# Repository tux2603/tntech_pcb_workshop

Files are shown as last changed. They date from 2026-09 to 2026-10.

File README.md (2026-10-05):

# tntech_pcb_workshop

Files and references for a PCB design workshop at Tennessee Tech. The workshop will focus on designing and assembling a two-layer PCB for a simple Arduino-compatible STM32 development board, and will serve as a first-introduction to PCB design and assembly for students. Students are expected to have a familiarity with basic electrical engineering concepts such as Ohm's law, impedance, and basic circuit analysis, but no prior experience with PCB design is required. The workshop will be hands-on, and will culminate in students assembling a (hopefully) functional PCB that they will be able to take home with them.

Additional information can be found in the [documentation](documentation/main.md) for the workshop. Slides shown in the workshop can be found in the [slides](documentation/slides/main.md) section of the documentation.

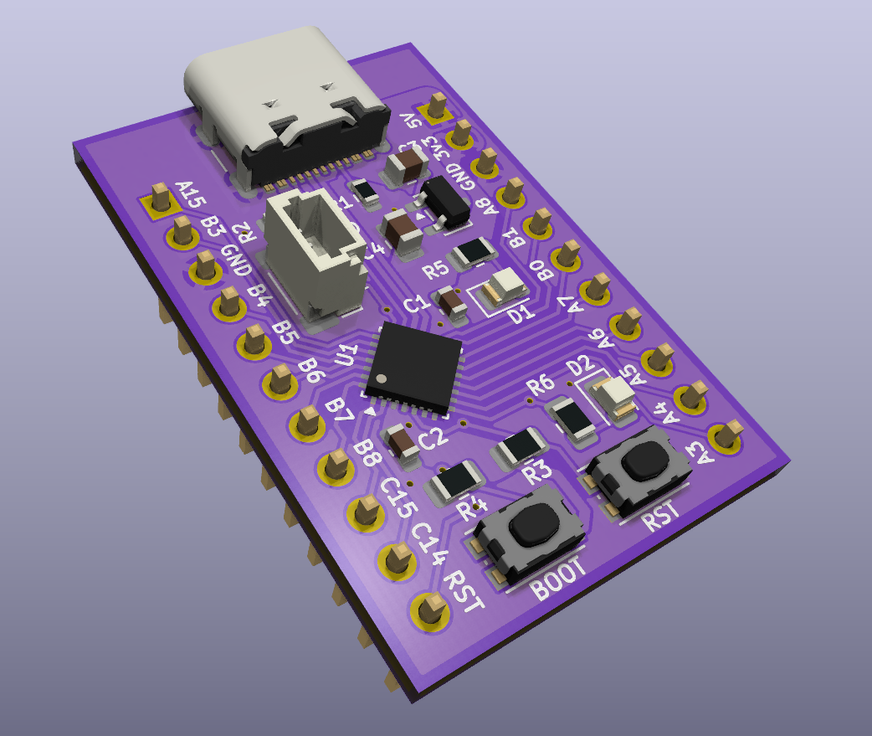
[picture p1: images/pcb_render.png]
PCB render


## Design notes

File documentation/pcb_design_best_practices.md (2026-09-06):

# Best Practices for PCB Designs

## 1. Designing with manufacturability and assembly in mind

A PCB isn't terribly useful if it only exists as some ones and zeroes on your computer. At every stage of the design process, you should be thinking about how your design will be manufactured, and if anything you're doing will make it difficult or impossible to produce. 

### 1.1 Design rules and other manufacturing considerations

- **Pick a target manufacturer early.** Every manufacturer has slightly different capabilities, which will affect many design decisions you make as you design the PCB. By picking a manufacturer early, you can make sure that your design is compatible with their capabilities, and avoid having to rework your design later.

- **Set up your design rules to match the capabilities of your manufacturer.** This is one of the most important steps in PCB design, and should be done before you start layout or routing. this includes minimum trace width and spacing, via sizes, and what sorts of vias are supported. Manufacturers can not reliably produce a PCB that violates their design rules, so if you don't set up your design rules correctly, you will almost certainly have to go back and rework your design before it can be manufactured. This sort of rework can be very time consuming and frustrating, so it's best to avoid it by setting up your design rules correctly from the start and checking them frequently as you work on your design.

- **Pick a stack-up early and stick with it.** A stack-up is the arrangement of copper and insulating layers in your PCB, along with a plan for how each copper layer will be used. The stack-up will affect the electrical performance of your design, the required traced widths for impedance-controlled signals, how easy it is to route your design, and the overall cost of manufacturing. Stack-ups will typically have one or more signal layers, each with a corresponding ground plane, and potentially one or more power planes. 

- **Avoid using the extreme limits of your manufacturer's capabilities when it's not necessary**. The capabilities of your manufacturer are only an absolute limit to what can be done. Just because your manufacturer can make 4 mil wide traces with 4 mil spacing doesn't mean that all your traces should be that small. Unless there is a specific reason to use a certain width trace, there's no reason to make your traces as small as possible. Wider traces are easier to manufacture, are more robust, and are easier to fix if something goes wrong. Set your default trace width to something reasonable, like 0.2-0.3 mm (~10 mil), and only use smaller traces when you have a reason to do so. Similarly, don't use the smallest possible via sizes unless you have a reason to do so.

- **Don't use high-end features like blind vias or super fine pitch traces unless you are sure that you need them for a design.** High-end features likes these can make a complex design possible, but will also cause the cost of manufacturing to skyrocket. If you can get away with the "lowest-tier" capabilities of your manufacturer, you should.

### 1.2 Component and footprint selection

- **Select components and footprints that are realistic for your assembly method.** If you are hand soldering, do not use tiny 0201 components. You _technically_ can solder them by hand, but it will be a nightmare. Through-hole components are easier to solder by hand, but they take up more space and are often more expensive.

- **Make sure that you have the right footprint for your selected components.** Components are often available in multiple different package types, each of which will require a different footprint on your PCB. Make sure that the footprint you are using matches the package type of the component that your are buying. If you are using a footprint that you found online, make sure to double check the dimensions of the footprint against the datasheet for the component to make sure that it is correct. 

- **Avoid using components that are difficult or cumbersome to source.** Doing this well takes a little experience, but you can get a basic idea of what is easy to source by looking at the stock levels and lifecycle of the components you are considering. If one option has 10,000 units in stock and another has 10, it is very likely that the first option will be more reliable to source in the long run. Similarly, if a component is marked as something like "End of Life," "Obsolete, "or "Not Recommended for New Designs", it will be extremely difficult to source in the future, and you should avoid using it if at all possible.

- **Avoid "Marketplace" style vendors when possible.** On sites like Digikey and Mouser, there are often "Marketplace" parts available at a lower price. These parts are typically sold and shipped by third-party sellers. They can potentially bring the overall cost of your design down, but will often have longer shipping times and require you to pay separate shipping charges. If you are on a tight schedule, it is often better to avoid marketplace parts.

### 1.3 Assembly considerations

- **Make sure that the pads for your components are on the correct layers.** You can't solder a component to a pad that is in the middle of a PCB. This means that your pads must be on either the top or bottom layer unless you are doing a very complex and extremely expensive custom designs.

- **Prefer to keep surface mount parts all on the same side of the board.** Single-sided assembly is cheaper and easier than double-sided assembly. If it doesn't matter what side of a board a component is on, pick a default side and stick with it. Typically the top layer is the standard for surface mount parts, but if it makes more sense to you to put everything on the bottom, that's fine too. Just make sure that you are consistent.

- **Avoid placing components too close together.** If components are too close together it can be extremely difficult to solder them, especially if you are hand soldering. Keep a reasonable buffer between components.

- **Avoid placing components too close to the edge of the board.** If components are too close to the edge of the board, they can be damaged during assembly or when the board is being handled. Unless your component needs to be on the edge of the board, for example if it's a connector or a button, keep them a reasonable distance back.

## 2. Designing with electrical performance in mind

While low-speed, low-power designs can often get away with a lot of "sloppy" design practices, high-speed or high-power designs will require careful attention to detail in order to function correctly. Even if your design is low-speed and low-power, it is still a good idea to follow best practices for electrical performance in order to form good habits that will carry over to more complex designs in the future.

### 2.1 Power distribution

- **Use a ground plane.** A ground plane is a large area of copper that is connected to the ground net of your design. A ground plane provides a reliable, low-impedance return path for signals and will make your design more robust to noise and interference and (hopefully) easier to route. On 4+ layer boards, it is extremely common to dedicate one or more entire layers to a solid ground plane. On 2-layer boards, it is a bit harder to dedicate an entire layer to a ground plane, but it is still extremely common to have one layer be mostly ground with as few other traces as possible. I can not stress enough how useful a ground plane is. Use a ground plane.

- **Use a "star" topology instead of a "daisy chain" topology for power distribution as much as possible.** A star topology is one where all the power connections to your components fan out from a single point, while a daisy chain topology is one where the power connections to your components are connected with a single trace, one after the other. A daisy chain topology will typically be easier to route, so it can be very tempting to use, but it can cause problems with accumulating voltage drops and noise as power travels down the chain. A star topology will typically require a bit more routing work, but will provide your components with a more stable and reliable power supply.

- **Use proper trace thicknesses based on your power needs.** If you are designing a high-power circuit, it is important to use traces that are thick enough to handle the current without overheating or causing voltage drops. There are many online calculators available that can help you determine the appropriate trace width based on the current and the thickness of your PCB copper layer.

- **Use decoupling capacitors near your ICs.** ICs will often draw large spikes of current as they switch states, which can cause glitches and brown-outs if your power distribution network isn't able to supply that current quickly enough. Decoupling capacitors are small capacitors placed as close to an IC's power pins as possible, and act as a local reservoir of charge that can supply the IC with power during these spikes. A good rule of thumb is to use a 0.1uF (100nF) ceramic capacitor for each power pin of an IC unless the IC's datasheet specifies otherwise. Connect one end of the decoupling capacitor to the IC's power pin, and connect the other end to the nearest ground plane.

### 2.2 Signal integrity

- **Route traces carrying your fastest/most sensitive signals first.** High-speed and impedance controlled signals will typically have the strictest routing requirements, so it is a good idea to get them out of the way first. Once you get traces routed for your high-speed signals, you can move on to routing traces for the rest of your signals.

- **Reference high-speed signals to an uninterrupted ground plane.** Anytime you have a current flowing through a trace, there must be a corresponding current flowing back to the source. If that current doesn't exist, it means that KCL is messed up and the universe has broken. Once the frequency components of a signal get high enough, this return current will no longer just follow the path of least resistance, but will instead follow the path of least impedance. The means that when you have a high-speed signal traveling along a trace, the return current will want to flow directly below that trace through the ground plane. If there is no ground plane below the trace or if the ground plane is interrupted by a gap, hole, or some other trace running through it, the return current will have to find some other path back to the source. This path is incredibly hard to predict, and can cause all sorts of problems with signal integrity, including reflections, crosstalk, and EMI.

- **Prefer referencing low-speed signals to a ground plane.** Low speed signals are not as sensitive to signal integrity issues as high-speed signals, but it is still a good idea to reference them to a ground plane whenever possible. It is possible to reference them to a power plane if a design requires it, but this is not ideal. If you do reference a low-speed signal to a power plane, make sure that you have decoupling capacitors close to the signal's source and load to complete the return path for the signal.

- **Use appropriate trace widths for impedance-controlled signals.** The width and spacing of a trace will affect the impedance that it presents to signals traveling along it. If you have an impedance mismatch between a trace carrying a high-speed signal and the source or load that it is connected to, you will get reflections and other signal integrity issues. Calculate the required trace width and spacing for your impedance controlled signals based on your PCB stack-up before you start routing, and make sure to use those widths and spacings when routing those traces.

- **Route differential pairs together and maintain their spacing.** Differential pairs are sets of two traces that carry a set of complementary signals. Differential pairs are often used for high-speed signals because they offer better noise immunity and produce less noise themselves. When routing differential pairs, it is important to keep the two traces close together and maintain a consistent spacing between them. 

## 3. Designing with testing and debugging in mind

### 3.1 Test points and indicators

- **Include indicator LEDs in your design.** In almost every situation, it is a good idea to include indicator LEDs in your design. LEDs, especially surface-mount LEDs, are extremely cheap and can provide an easy visual indicator of things like power, status, and detected errors. If you have any sort of power regulation in your design, it is a good idea to include a power indicator LED. If your design is using some for of microcontroller, it is a good idea to use spare GPIO pins from that microcontroller to drive status LEDs. It's a lot faster to glance at a board and see that an LED is lit or blinking than it is to grab a multimeter or oscilloscope and start probing around to try and figure out what is going on.

- **Include test points for important nets on your PCB.** While status LEDs are useful, you sometimes do need a bit more information than a simple on/off indicator can provide. In these situations, it is a good idea to include test points in your design. Test points are small pads that are connected to important signals or power planes, and provide a convenient place to probe with a multimeter or oscilloscope

### 3.2 Documentation

- **Keep track of design decisions and changes.** Documenting your design decisions and any changes made during the design process is crucial for maintaining a clear understanding of the design and for future reference. You don't want to go back to your design a few weeks later and try to remember if there was a reason you're using a 19k resistor, or if it was just a typo.

- **Use silkscreen labels as much as possible** Silkscreen labels are the text and symbols printed on the surface of your PCB. They can be used to label components, indicate pin numbers, and provide other useful information. If you have extra space, mark down what pins are being used for what purpose, or any other useful information. This will make it easier to debug your design later, and will also make it easier for someone else to understand your design if they need to work on it in the future.

- **Use version control for your PCB design files.** Version control, such as git, is a system that makes it easy to track changes to files over time. Using version control will not only provide an overview of the changes you've made over time, but will also make it easier to revert to a previous version of your design if you make a mistake or decide that the changes you made weren't actually necessary. 

### 3.3 "Flexible" design

- **Design your PCB to be easily modified post-manufacturing.** Chances are the first iteration of a PCB design will not be perfect, and you'll likely have to make some tweaks. For prototypes, you can work in some design elements to make these tweaks easier. Typically, this will mean leaving some extra space around components, using thicker traces, providing test pads for important nets, and avoiding routing signals on internal layers. Copper is effectively free on a PCB, so there's not much reason to be stingy with it. If you have the space, use it to make your design easier to tweak.

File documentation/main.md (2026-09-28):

# Tennessee Tech PCB Design Workshop

## Overview

This workshop is designed to provide hands-on experience with PCB design and manufacturing processes. Participants will learn how to design a PCB using industry-standard software, understand the manufacturing process, and how to follow best practices for creating reliable and efficient PCB layouts. Due to time constraints, this workshop will not go over schematic capture or simulation, nor will it cover advanced topics such as high-speed design, RF design, or power electronics. Instead, the focus will be on the fundamentals of PCB design, including layout techniques, component placement, routing strategies, and design for manufacturability.

In the workshop, participants will be guided through the process of designing a simple PCB starting from a provided schematic. The goal will be to create a functional PCB layout that can be manufactured and assembled. The schematic used in this workshop is a simple microcontroller dev-board based on the STM32C071RB6N from STMicroelectronics. This microcontroller is a 32-bit ARM Cortex-M0+ device capable of running at up to 48 MHz with 128 kB of flash memory, 16 kB of SRAM. This device is suitable for a wide range of applications, and was selected because it can be programmed using a built-in USB DFU bootloader without the need for an external crystal or expensive programming tools. The final board can be programmed directly from the Arduino IDE, but will also work with other programming environments such as PlatformIO, STM32CubeIDE, and Keil MDK.

## Workshop Goals

By the end of this workshop, participants will be able to:
- Understand the basics of PCB design and layout.
- Use PCB design software to create a PCB layout from a schematic.
- Apply best practices for component placement, routing, and design for manufacturability.
- Prepare a PCB design for manufacturing, including generating Gerber files and a Bill of Materials (BOM).
- Assemble and test a simple PCB design.

## Workshop Materials and Resources

The only thing that participants will need to bring to the workshop is a laptop with KiCad 10.0 installed. KiCad is a free and open-source PCB design software that is widely used, both in the industry and by hobbysists. KiCad is available for Windows, MacOS, and Linux, and can be downloaded from the official KiCad website: [https://kicad.org/download/](https://kicad.org/download/). Participants are encouraged to install KiCad prior to the workshop to ensure that they have the latest version and that it is working properly on their system. All other materials, including the PCB and all components needed for the workshop, will be provided by the workshop organizers.

If you would like to assemble the PCB after the workshop, all of the parts are available for purchase from DigiKey, Mouser, or other electronics distributors. A boll of materials (BOM) for the PCB is provided [In this repository](../Tech%20PCB%20BOM.csv), and a DigiKey parts list is available [here](https://www.digikey.com/en/mylists/list/NAWFEKVTE1). Additional PCBs can be purcased from any major PCB manufacturer, such as [JLCPCB](https://jlcpcb.com/), [PCBWay](https://www.pcbway.com/), [OSH Park](https://oshpark.com/), or [DKRed](https://www.digikey.com/en/resources/dkred).

A quick reference guide to PCB design best practices can be found in the [PCB Design Best Practices](pcb_design_best_practices.md) document. Slides from the workshop will be uploaded in the future.

## External Resources

- **[KiCad Documentation](https://docs.kicad.org/)**: The official documentation for KiCad, including tutorials and reference materials.
- **[Phil's Lab YouTube Channel](https://www.youtube.com/@PhilsLab)**: A YouTube channel with tutorials and videos on PCB design, electronics, and related topics.

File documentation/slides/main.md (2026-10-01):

# Workshop Slides

- **Session 1**: [PCB Design intro and best practices](s1_slides.pdf)

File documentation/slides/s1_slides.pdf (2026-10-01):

# Tennessee Tech PCB Design Workshop

Owen O’Connor (ococonnor42@tntech.edu)

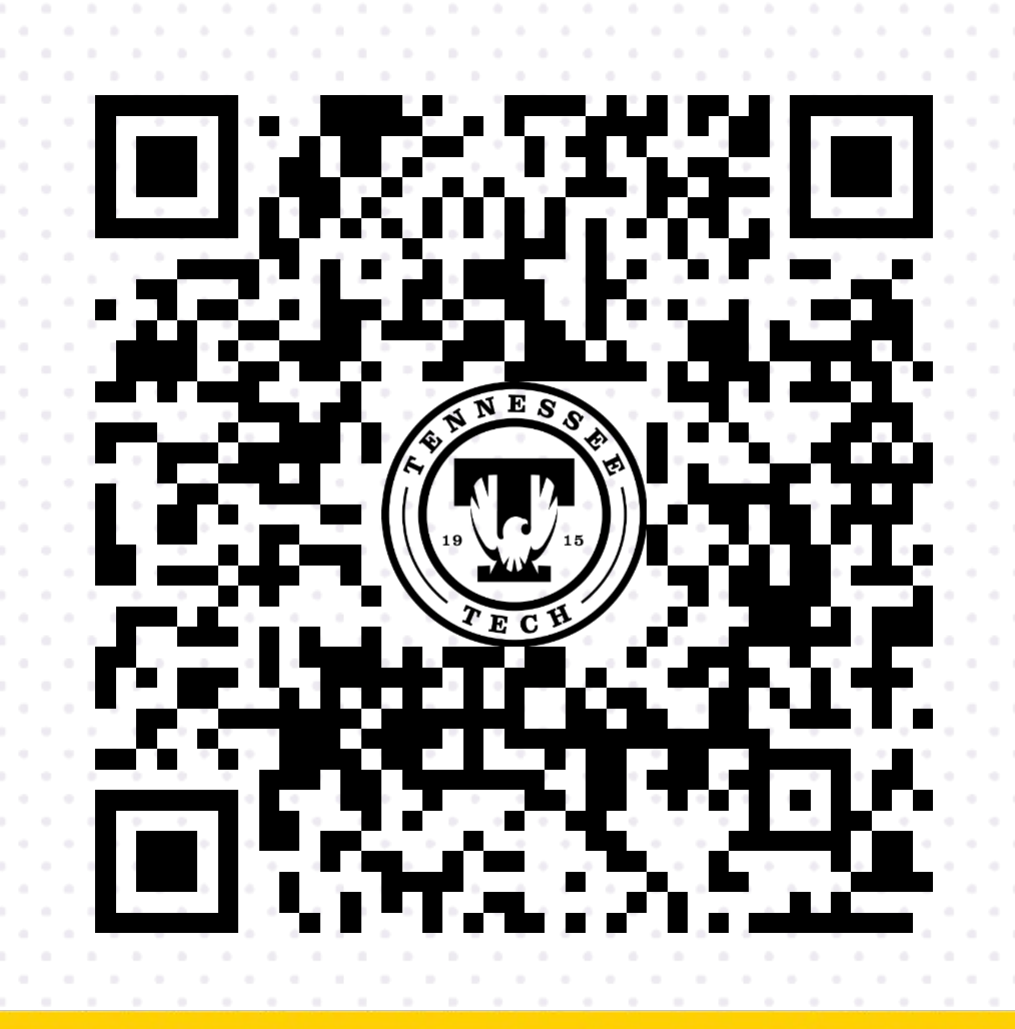
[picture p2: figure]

1

## Workshop Overview

- PCB Design Principles and Practices (1 October) ← today!
- PCB Design Time in KiCad (6 October)
- PCB Design Time in KiCad (8 October)
- PCB Assembly and Testing (13 October*)

*tentative date

2

## Workshop Goals

- Why and when to use PCBs
- PCB design best practices
- Using PCB design software
- Assembling PCBs

3

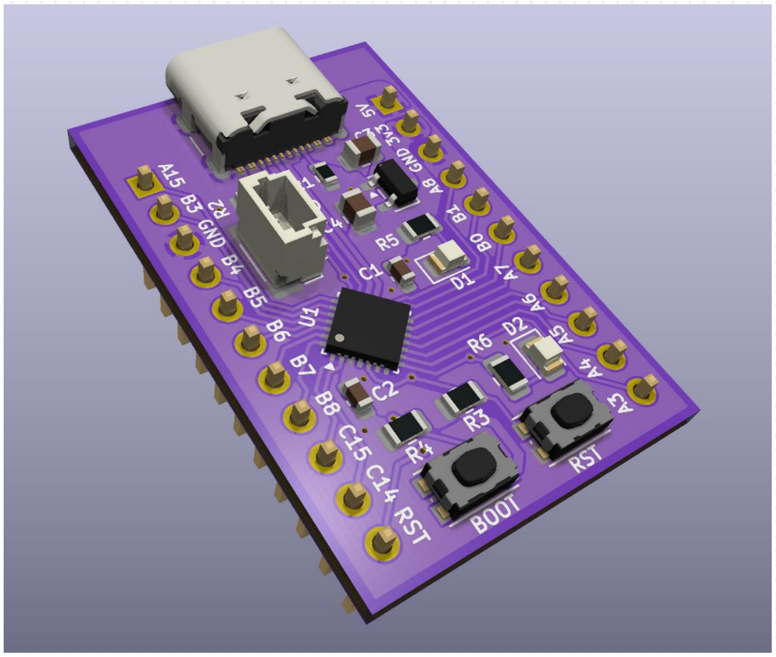
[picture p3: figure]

## Our Project

STM32 board,
Arduino-compatible
- USB-C
- 17 (kinda 18) GPIO
- Built in LED
- Debug Header

4

## Today’s Goals

- Understand why PCBs are important
- Learn the PCB design workflow
- PCB design best practices
- How to install KiCad

5

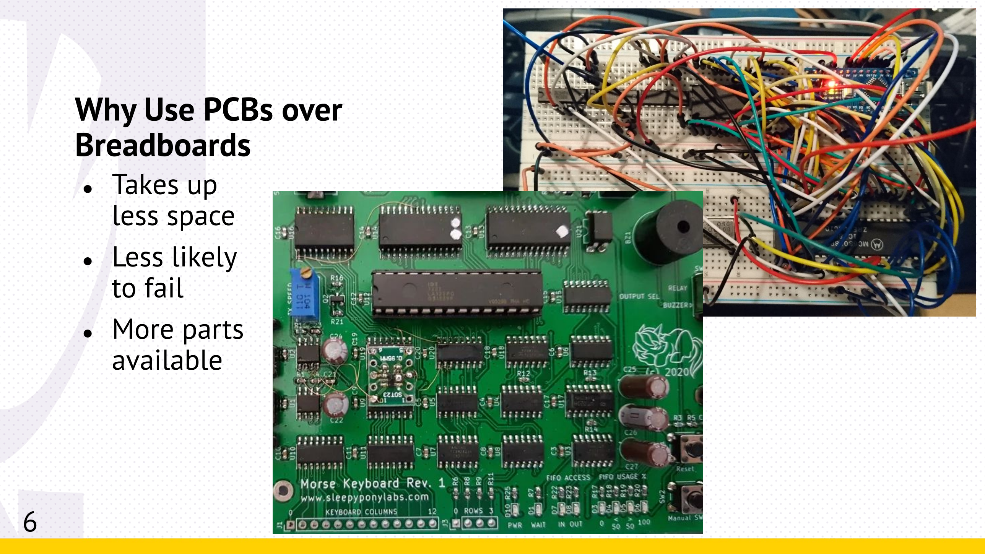
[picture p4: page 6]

### Why Use PCBs over Breadboards

- Takes up
less space
- Less likely
to fail
- More parts
available

6

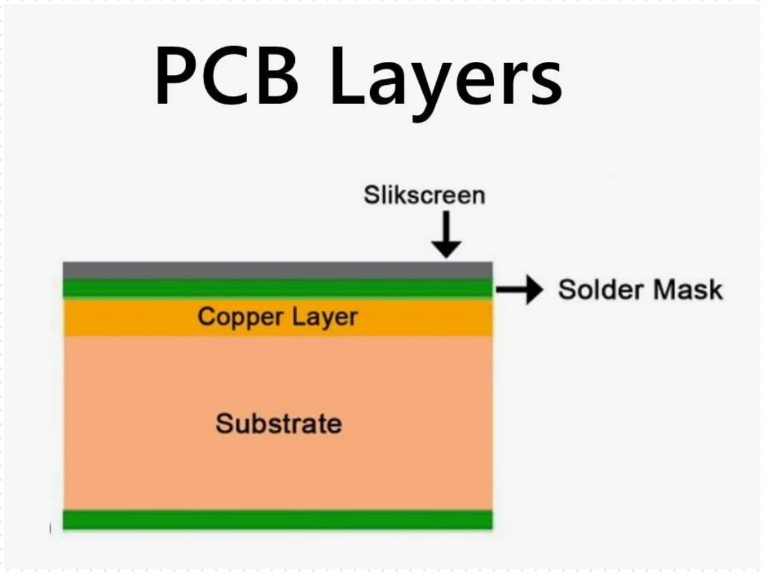
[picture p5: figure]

### Layers of a PCB

- Copper
- Substrate
- Solder mask
- Silkscreen

7

### Features on a PCB

- Pad
- Trace
- Via
- Plane
- Footprint

8

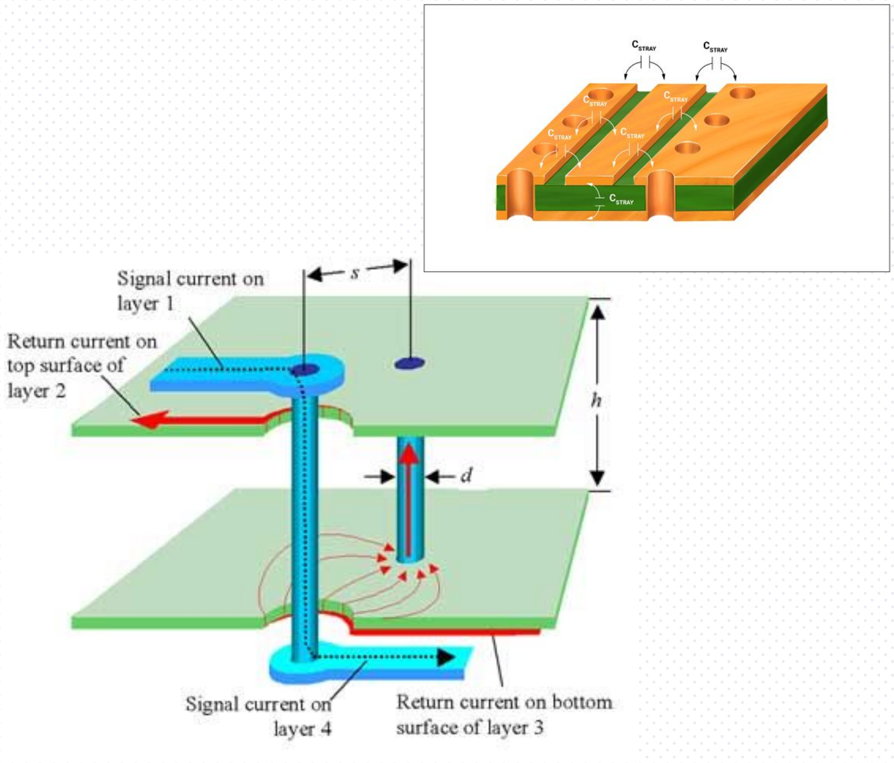
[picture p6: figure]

### The Electrical Behavior of a PCB

- Return currents (low
vs high speed)
- Current loops
- Parasitic capacitance

9

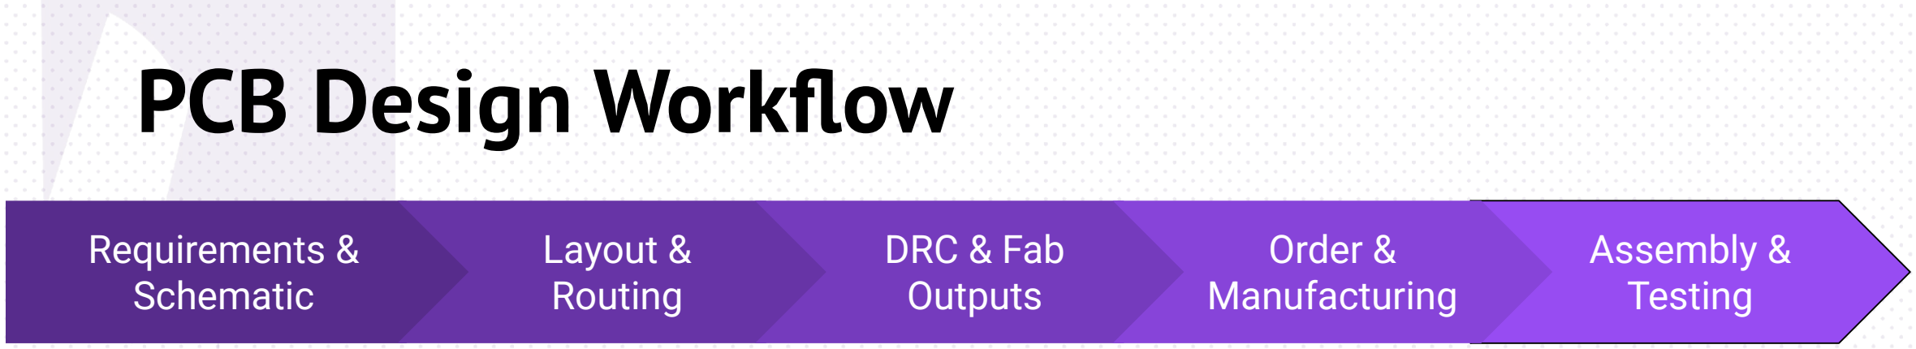
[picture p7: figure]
PCB Design Workflow; Requirements & Schematic; Layout & Routing; DRC & Fab Outputs; Assembly & Testing; Order & Manufacturing

- Figure out what
the board does
- Figure out how
to do that thing
- Plan out how to
connect
everything in
order to do that
thing
- Defines the
physical size of
the board
- Plan the layout
so routing is
easy
- Route traces to
connect
everything
together
- Verify that your
design can be
made
- Export the
design files for
sharing
- Place and solder
components
- Test for shorts and
connections
- Upload any code,
verify functionality
- Upload exported
design files
- Fill out requested
specs and
features
- Place order

10

## Schematics

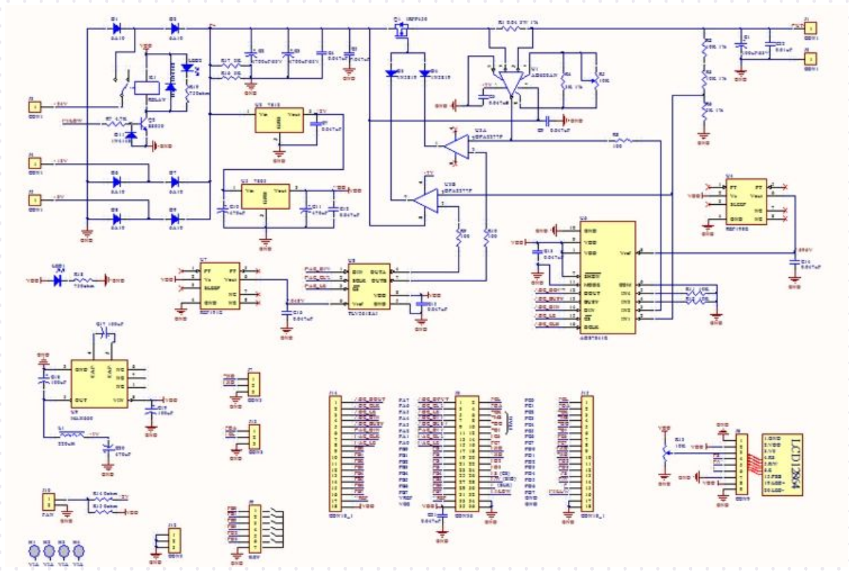
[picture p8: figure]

Left to right flow
Power is up, ground is down Group by function
Documentation!

11

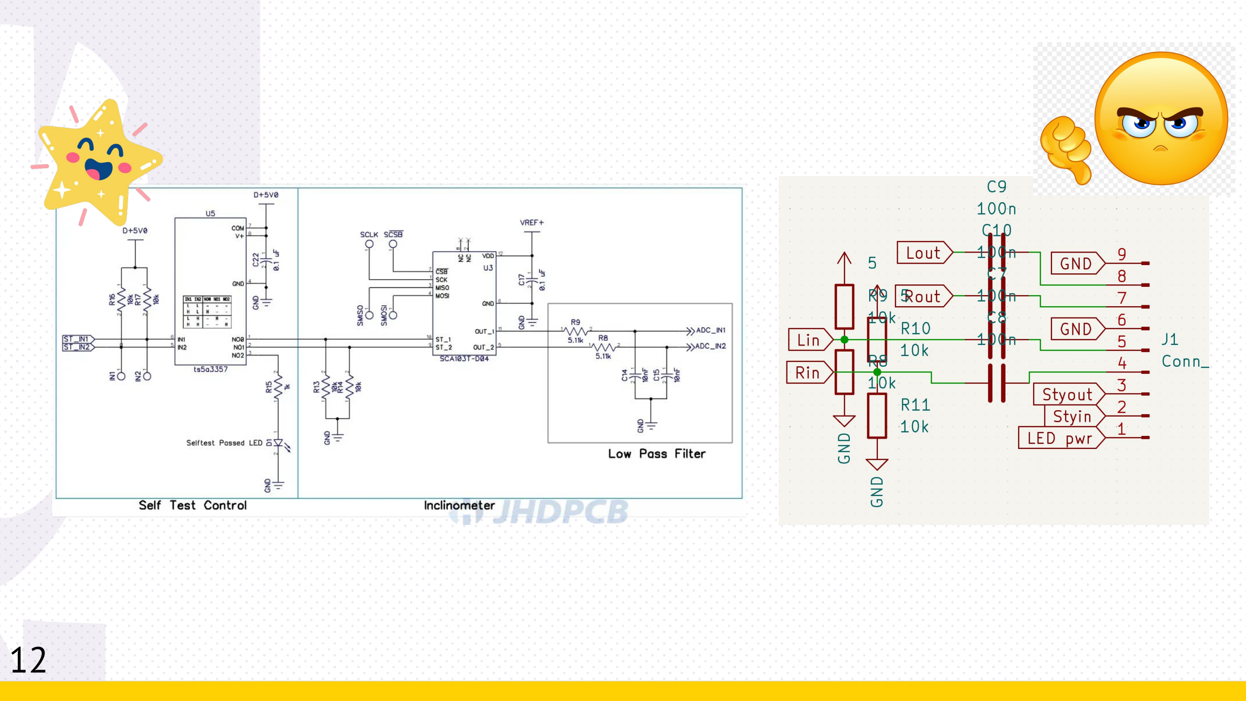
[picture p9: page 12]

12

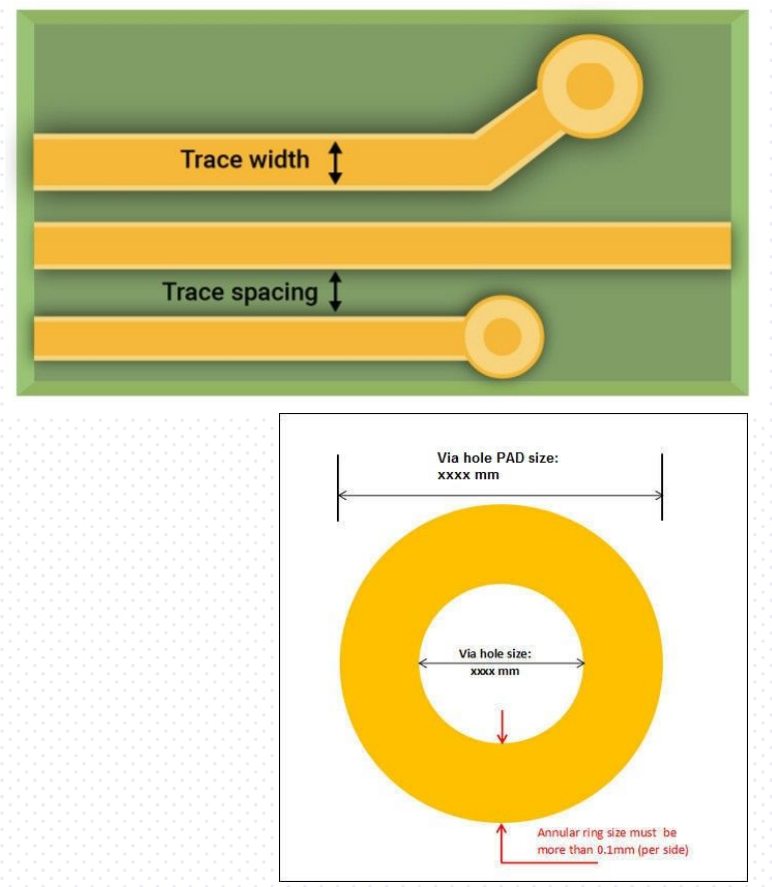
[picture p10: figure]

## Design Rules

Always set these up!
- Minimum trace width/spacing
- Minimum via size
- Clearance requirements
- Etc

Minimums are just minimums! Typically you want to use greater than the minimum
13

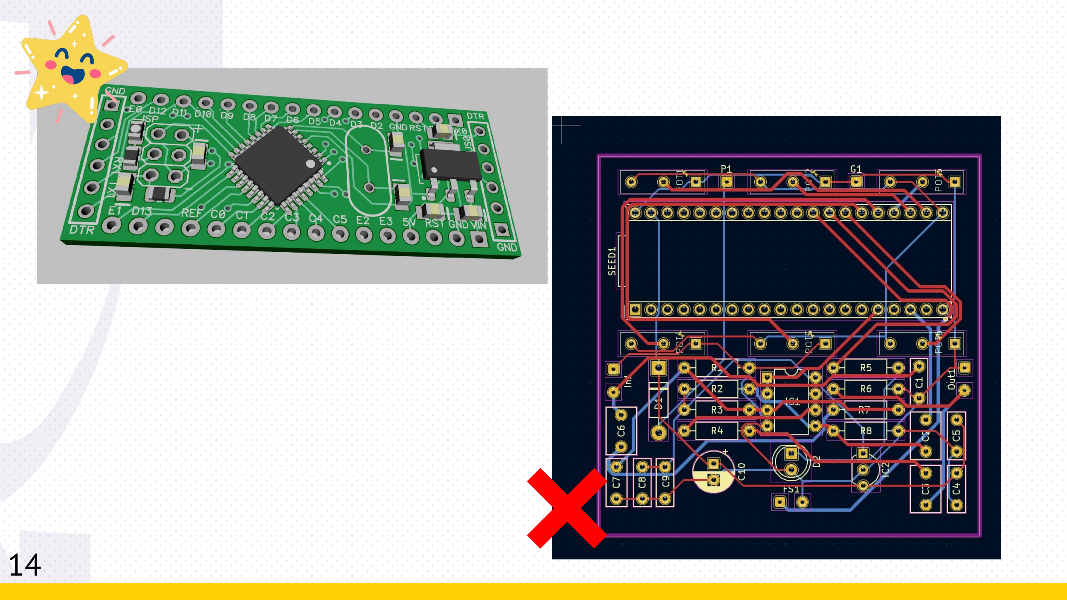
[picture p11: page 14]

14

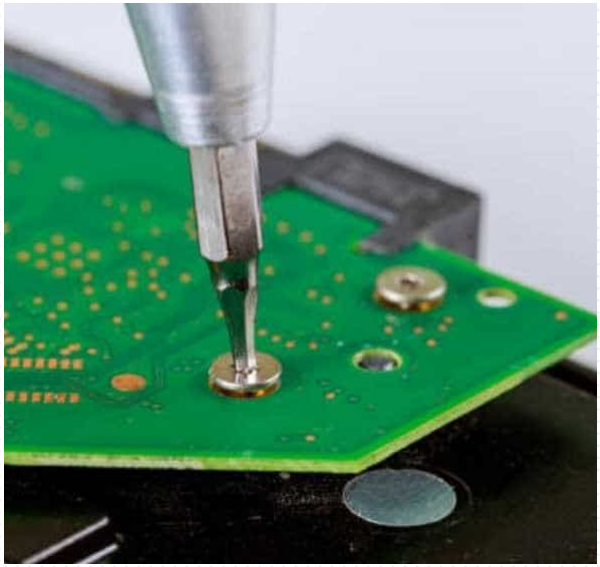
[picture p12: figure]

## Physical Aspects

Outline/edge cuts
Connector placement
Mounting holes

15

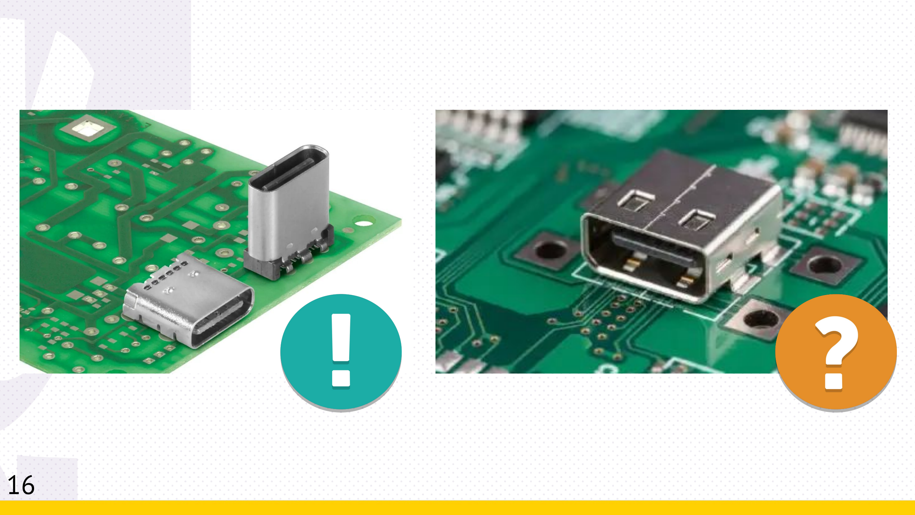
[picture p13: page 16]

16

## Stack up

Number of layers
Purpose of each layer
Common stackups:

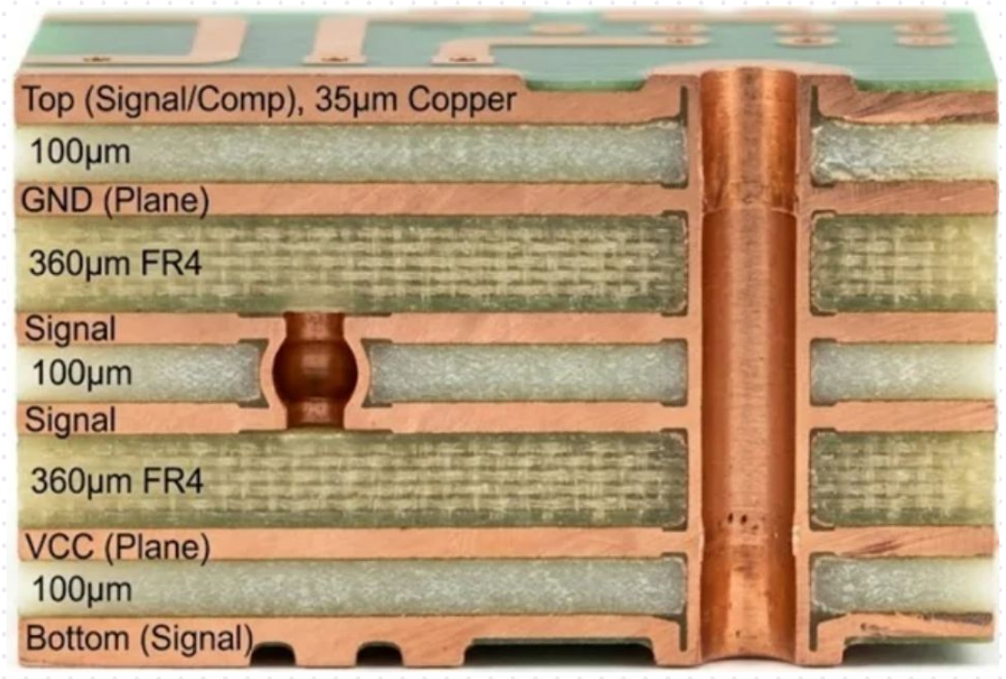
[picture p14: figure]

2 Layer | 4 Layer | 6 Layer

Sig+PWR
GND

Sig+PWR
Sig+GND

Sig
| GND GND

Sig

Sig
| GND PWR Sig (slow)

Sig
| | GND PWR

Sig
| | GND
Sig

Sig
Gnd
Sig
Sig
Pwr
Sig 17

## Footprint/Component Selection

Choose appropriate footprints
Check dimensions from against the data sheet Check pin orders on multi-pin parts

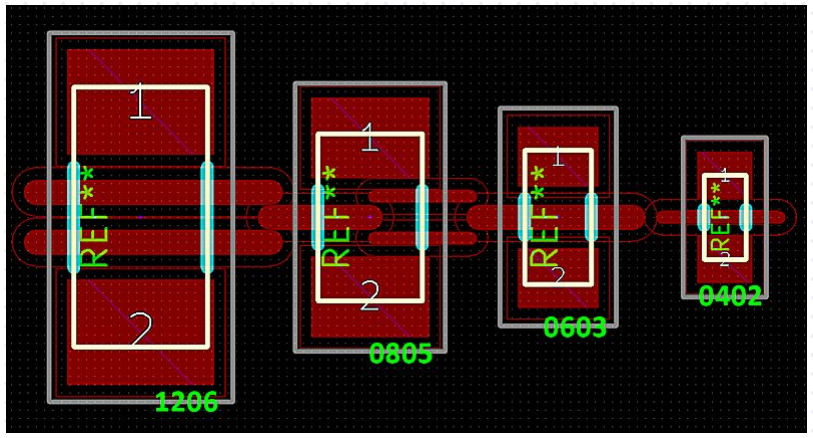
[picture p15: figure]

Note: The number refers to the dimensions of the 18 component (ex. 0603 => 60x30 thousandths of an inch)

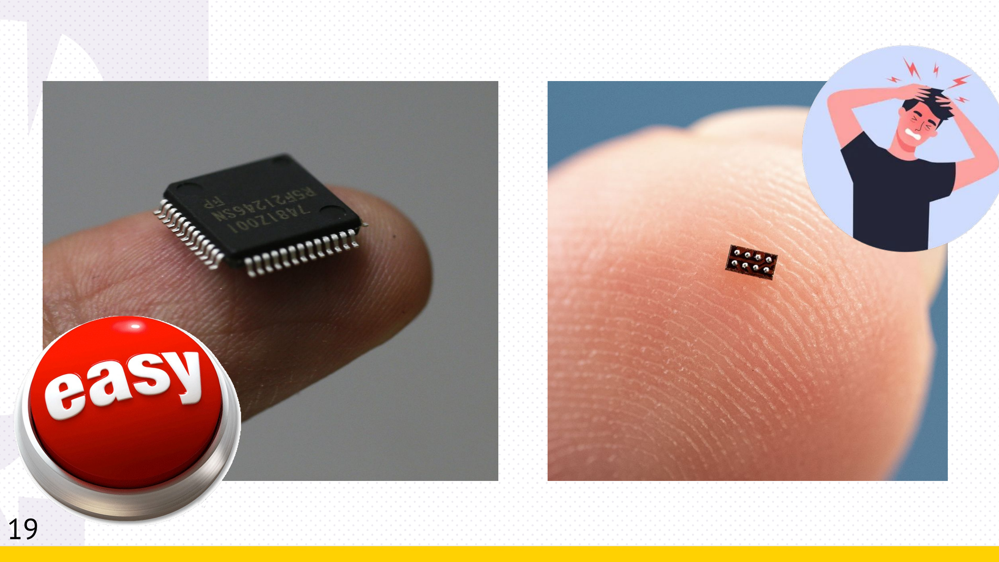
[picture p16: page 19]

19

## Layout

- Placement by functional groups
- Decoupling caps
- Minimize ratline crossing

Falstad Simulation (https://falstad.com/circuit/circuitjs.html) of decoupling capacitor

20

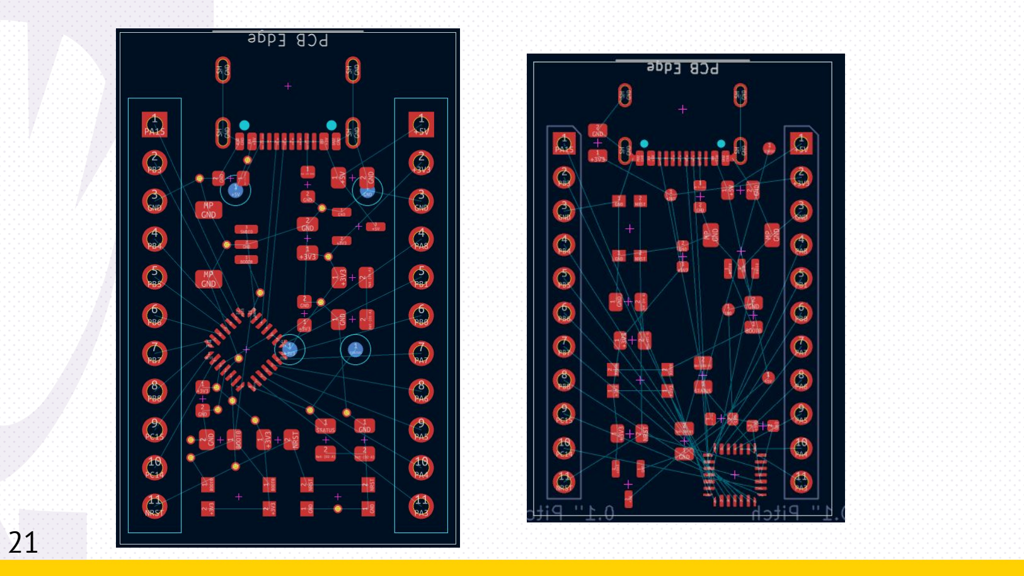
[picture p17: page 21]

21

## Power Distribution

- Solid ground plane whenever possible
- Solid power plane when you can
- Star instead of daisy chain power distribution
- (again) Decoupling capacitors!

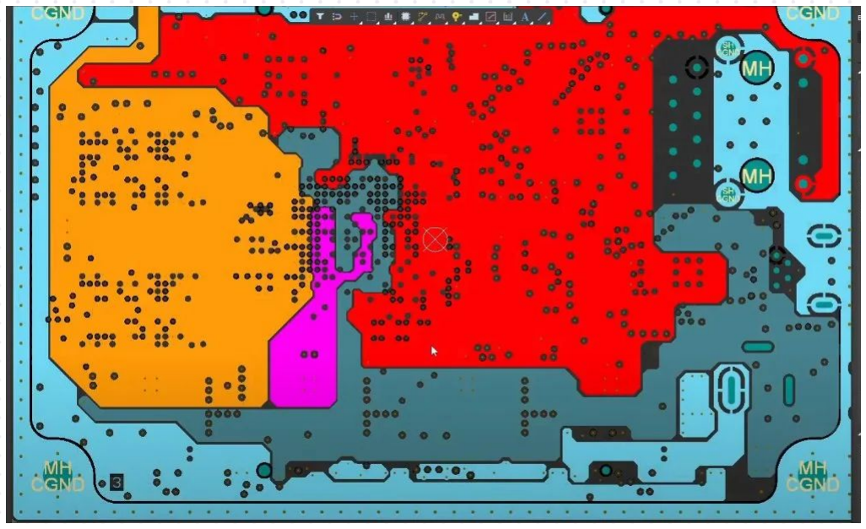
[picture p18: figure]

22

## Signal Integrity and Reliability

- Decoupling caps close to all ICs (this is important)
- Reference plane for high speed signals
- Place and route most sensitive signals first
- Impedance/length matching

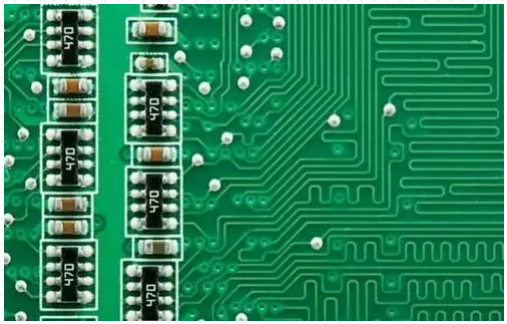
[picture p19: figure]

23

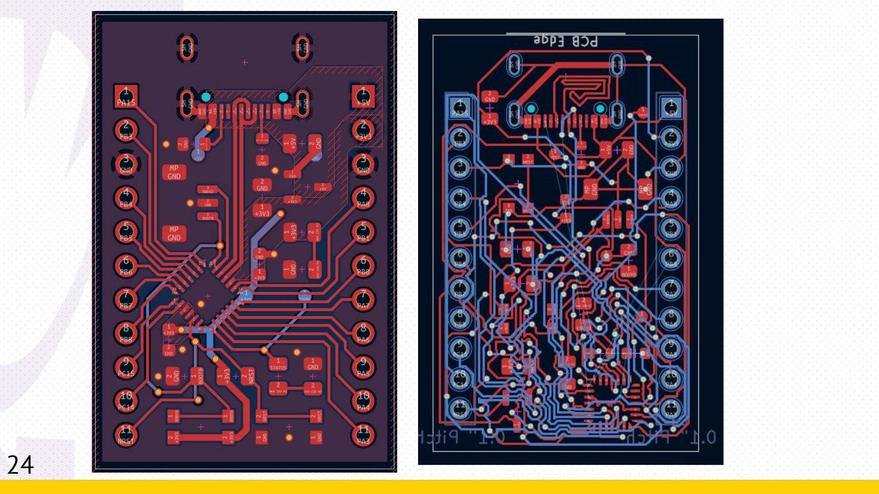
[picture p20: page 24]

24

## Manufacturability

- No vias in pads!
- Have some space between components
- Aim for one-sided designs

25

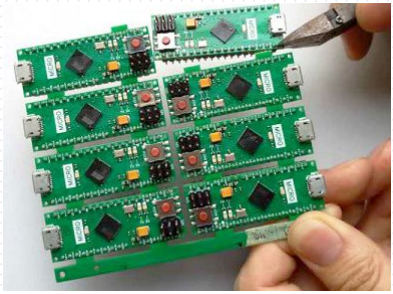
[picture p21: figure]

## Debuggable Designs

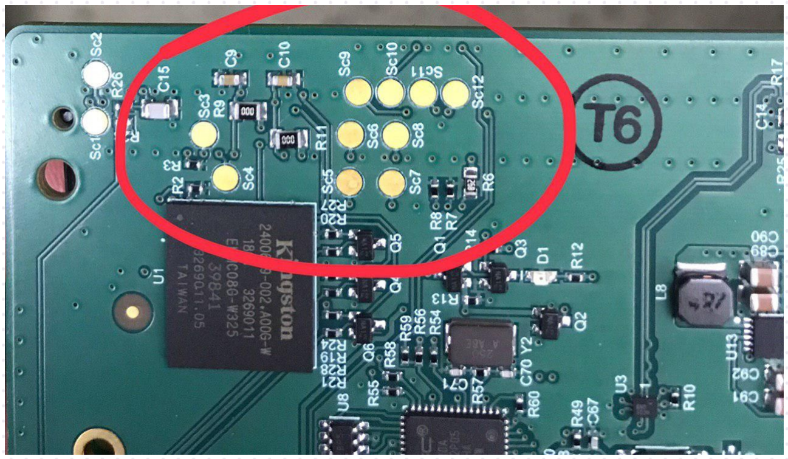
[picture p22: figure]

- Lavish use of silkscreen
(it’s free!)
- Test points
(it’s free!)
- Power/Status LEDs
(it might as well be free!)

26

## Flexible Designs

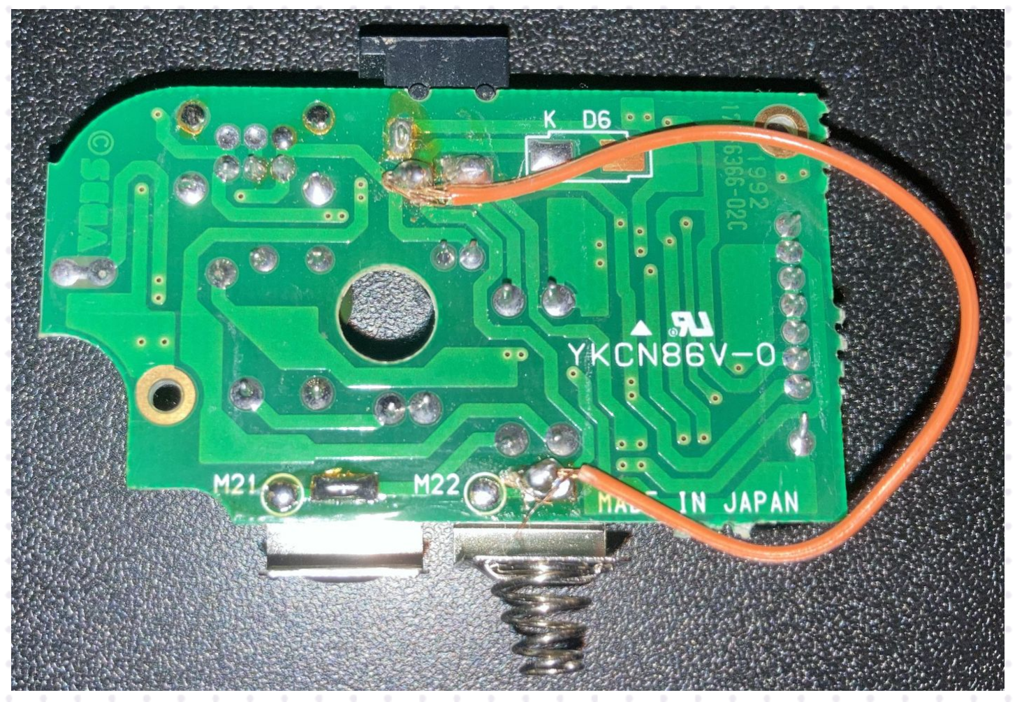
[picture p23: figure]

- Not sure if you need a part? Add it anyway
(Footprints are free!)
- Extra pins? Break them out
(Footprints are free!)
- Thicker signal traces, routed on the outside
(It’s easier to bodge thicker traces)

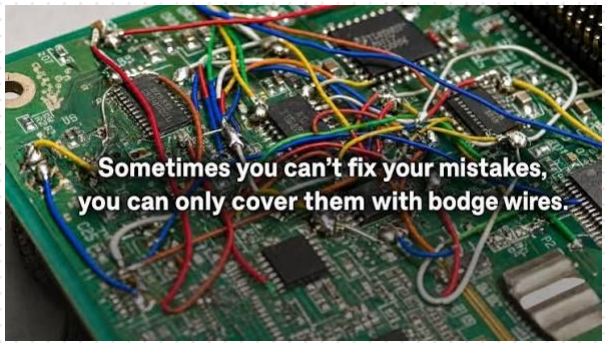
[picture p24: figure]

27

## Before next session!

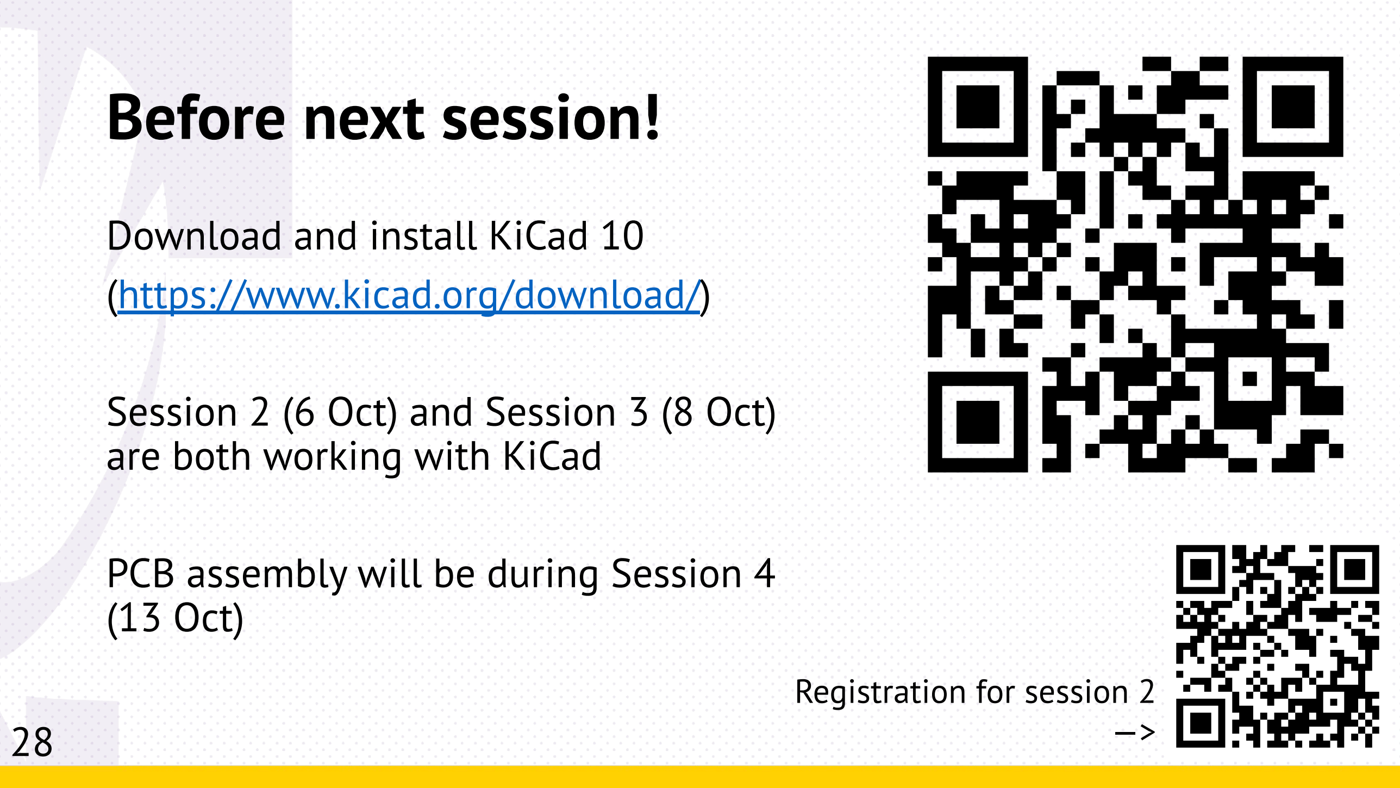
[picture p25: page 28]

Download and install KiCad 10 (https://www.kicad.org/download/)

Session 2 (6 Oct) and Session 3 (8 Oct) are both working with KiCad

PCB assembly will be during Session 4 (13 Oct)

Registration for session 2 —> 28

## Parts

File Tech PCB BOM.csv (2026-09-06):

Index | Manufacturer Part Number | Manufacturer Name | Description | Customer Reference | Attrition % | Requested Quantity 1 | Pack Quantity 1 | Pack Type 1 | Digi-Key Part Number 1 | Unit Price 1 | Extended Price 1 | Minimum Order Quantity 1 | Reference Designator | Product Notes
1 | STM32C071GBU6N | STMicroelectronics | MAINSTREAM ARM CORTEX-M0+ MCU WI | Main MCU | 10 | 1 | 2 | Tray | 497-STM32C071GBU6N-ND | 1.88000 | $3.76 | 1 | U1
2 | XC6206P332MR | UMW | IC REG LINEAR 3.3V 100MA SOT23 | Voltage Regulator | 5 | 1 | 2 | Cut Tape (CT) | 4518-XC6206P332MRCT-ND | 0.10000 | $0.20 | 1 | U2
3 | CL10B104KO8NFNC | Samsung Electro-Mechanics | CAP CER 0.1UF 16V X7R 0603 | Decoupling Caps | 25 | 2 | 3 | Cut Tape (CT) | 1276-1938-1-ND | 0.10000 | $0.30 | 1 | C1, C2
4 | CL21B105KAFNFNE | Samsung Electro-Mechanics | CAP CER 1UF 25V X7R 0805 | Bulk Caps | 25 | 2 | 3 | Cut Tape (CT) | 1276-2926-1-ND | 0.11000 | $0.33 | 1 | C1, C2
5 | RC0603JR-075K1L | YAGEO | RES 5.1K OHM 5% 1/10W 0603 | USB-C CC Resistors | 25 | 2 | 3 | Cut Tape (CT) | 311-5.1KGRCT-ND | 0.11000 | $0.33 | 1 | R1, R2
6 | RC0805JR-0710KL | YAGEO | RES 10K OHM 5% 1/8W 0805 | Pull-up/Pull-down Resistors | 25 | 2 | 3 | Cut Tape (CT) | 311-10KARCT-ND | 0.10000 | $0.30 | 1 | R3, R4
7 | RC0805JR-07220RL | YAGEO | RES 220 OHM 5% 1/8W 0805 | LED Resistors | 25 | 2 | 3 | Cut Tape (CT) | 311-220ARCT-ND | 0.10000 | $0.30 | 1 | R5, R6
8 | LTST-C171YKT | Lite-On Inc. | LED YELLOW CLEAR CHIP SMD | Indicator LEDs | 10 | 2 | 3 | Cut Tape (CT) | 160-1431-1-ND | 0.13000 | $0.39 | 1 | D1, D2
9 | Y78B62324FP | C&K | KMR GOLD PLATED TACTILE SWITCH | Pushbuttons | 10 | 2 | 3 | Cut Tape (CT) | 108-Y78B62324FPCT-ND | 0.80000 | $2.40 | 1 | SW1, SW2 | No Backorders Allowed.
10 | PH1-11-UA | Adam Tech | CONN HEADER VERT 11POS 2.54MM | Breadboard Headers | 5 | 2 | 3 | Bag | 2057-PH1-11-UA-ND | 0.17000 | $0.51 | 1 | J1, J2
11 | USB4105-GF-A | GCT | CONN RCP USB2.0 TYP C 16P SMD RA | USB-C Header | 5 | 1 | 2 | Cut Tape (CT) | 2073-USB4105-GF-ACT-ND | 0.80000 | $1.60 | 1 | J3
12 | BM03B-SRSS-TB | JST Sales America Inc. | CONN HEADER SMD 3POS 1MM | SWD Header | 5 | 1 | 2 | Cut Tape (CT) | 455-BM03B-SRSS-TBCT-ND | 0.46000 | $0.92 | 1 | J4

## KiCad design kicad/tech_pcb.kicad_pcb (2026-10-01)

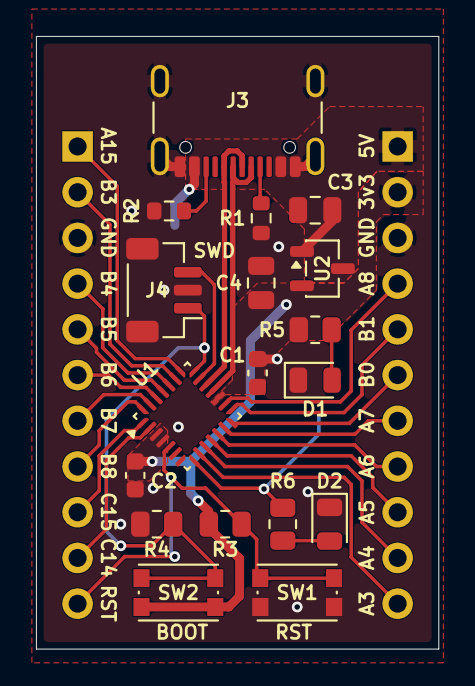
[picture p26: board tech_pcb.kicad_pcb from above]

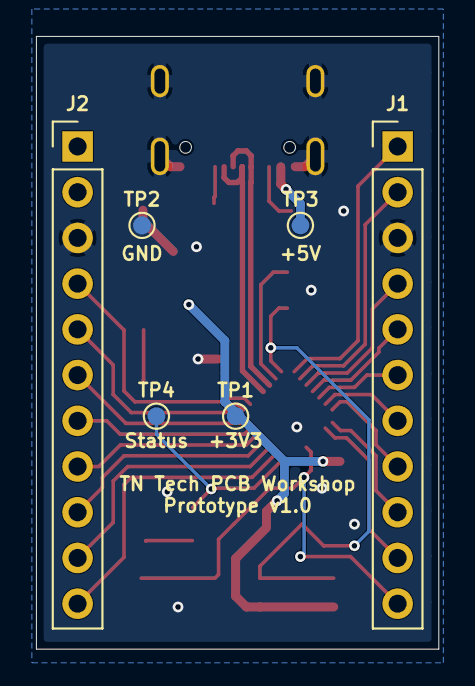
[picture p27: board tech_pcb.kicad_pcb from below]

Board: 2 copper layers, 22.4 x 34.0 mm, 24 parts (6 on the bottom side), 30 nets.

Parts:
C1, C2: 100n; C_0603_1608Metric
C3, C4: 1u; C_0805_2012Metric
D1: PWR; LED_0805_2012Metric
D2: STATUS; LED_0805_2012Metric
J1, J2: Conn_01x11; PinHeader_1x11_P2.54mm_Vertical
J3: USB_C_Receptacle_USB2.0_16P; USB_C_Receptacle_GCT_USB4105-xx-A_16P_TopMnt_Horizontal
J4: Conn_01x03_MountingPin; JST_SH_BM03B-SRSS-TB_1x03-1MP_P1.00mm_Vertical
R1, R2: 5k1; R_0603_1608Metric
R3, R4: 10k; R_0805_2012Metric
R5, R6: 220; R_0805_2012Metric
SW1: RST; SW_Push_1P1T_NO_CK_KMR2
SW2: BOOT; SW_Push_1P1T_NO_CK_KMR2
TP1, TP2, TP3, TP4: TestPoint; TestPoint_Pad_D1.0mm
U1: STM32C071GBUxN; QFN-28_4x4mm_P0.5mm
U2: XC6206PxxxMR; SOT-23-3

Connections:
+3V3: C1.1, C2.1, C4.1, J2.2, R3.1, R5.1, SW2.2, TP1.1 (1_1), U1.3 (VDD), U1.17 (VDDIO2), U2.2 (VO)
+5V: C3.1, J2.1, J3.A4 (VBUS), J3.A9 (VBUS), J3.B4 (VBUS), J3.B9 (VBUS), TP3.1 (1_1), U2.3 (VI)
/BOOT0: J4.1, R4.1, SW2.1, U1.21 (PA14)
/NRST: J1.11, R3.2, SW1.2, U1.5 (PF2)
/PA3: J2.11, U1.9 (PA3)
/PA4: J2.10, U1.10 (PA4)
/PA5: J2.9, U1.11 (PA5)
/PA6: J2.8, U1.12 (PA6)
/PA7: J2.7, U1.13 (PA7)
/PA8: J2.4, U1.16 (PA8)
/PA15: J1.1, U1.22 (PA15)
/PB0: J2.6, U1.14 (PB0)
/PB1: J2.5, U1.15 (PB1)
/PB3: J1.2, U1.23 (PB3)
/PB4: J1.4, U1.24 (PB4)
/PB5: J1.5, U1.25 (PB5)
/PB6: J1.6, U1.26 (PB6)
/PB7: J1.7, U1.27 (PB7)
/PB8: J1.8, U1.28 (PB8)
/PC14: J1.10, U1.2 (PC15)
/PC15: J1.9, U1.1 (PC14)
/STATUS: R6.1, TP4.1 (1_1), U1.8 (PA2)
/SWDIO: J4.3, U1.20 (PA13)
/USB_DN: J3.A7 (D-), J3.B7 (D-), U1.18 (PA11)
/USB_DP: J3.A6 (D+), J3.B6 (D+), U1.19 (PA12)
GND: C1.2, C2.2, C3.2, C4.2, D1.1 (K), D2.1 (K), J1.3, J2.3, J3.A1 (GND), J3.A12 (GND), J3.B1 (GND), J3.B12 (GND), J3.SH (SHIELD), J4.2, J4.MP (MountPin), R1.2, R2.2, R4.2, SW1.1, TP2.1 (1_1), U1.4 (VSS), U2.1 (GND)
unnamed: D1.2 (A), R5.2
unnamed: D2.2 (A), R6.2
unnamed: J3.A5 (CC1), R1.1
unnamed: J3.B5 (CC2), R2.1

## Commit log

2026-08-19 Update part selections and add BOM
    [Tech PCB BOM.csv, tech_pcb.kicad_pcb, tech_pcb.kicad_sch]
2026-08-21 Add SVG output for solder stencils
2026-08-24 Fix via sizes for osh park
    [tech_pcb.kicad_pcb]
2026-09-01 Update board to v0.2
    [tech_pcb.kicad_pcb, tech_pcb.kicad_sch]
2026-09-01 Update BOM to v0.2
    [Tech PCB BOM.csv, tech_pcb.kicad_pcb]
2026-09-02 Add silkscreen labels to all pins
    [tech_pcb.kicad_pcb]
2026-09-02 Forgot to run DRC
    [tech_pcb.kicad_pcb]
2026-09-04 Tidy up the schematic
    [tech_pcb.kicad_pcb, tech_pcb.kicad_sch]
2026-09-06 Start adding documentation
    [tech_pcb.kicad_pcb]
2026-09-06 Fix BOM to show 11 pin header
    [Tech PCB BOM.csv]
2026-09-15 Bump to v1.0
    [tech_pcb.kicad_pcb]
2026-10-01 Fix routing to move power trace running adjacent to USB data return current
    [tech_pcb.kicad_pcb]
2026-10-05 Added Temp Kicad File
    File used when learning layout and routing
2026-10-05 Kicad Cheat Sheet
